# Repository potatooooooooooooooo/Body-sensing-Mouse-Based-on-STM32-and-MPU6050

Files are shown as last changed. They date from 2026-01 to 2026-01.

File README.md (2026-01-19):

## 项目简介
本项目是基于STM32和MPU6050的体感鼠标。项目通过使用Mahony算法实现姿态解算，利用无线模块实现数据传输，并最终实现了航姿仪姿态数据的实时解算与体感鼠标的姿态感应控制。

>本项目为本科课设，没想到过了近两年还有同学记得这个项目，于是直接开源到这里。
>当时做的比较简陋，欢迎大家在此基础上各显神通，做出更多好玩的东西。

## 项目功能
1.STM32采集传感器的数据，对姿态信息进行解算，并通过OLED屏幕进行显示，角度差小于1°。
2.按键控制LED灯的呼吸效果。
3.航姿仪系统发射端和体感鼠标接收端的板间通信，由无线模块接收姿态信息。
4.通过USB接口驱动电脑鼠标移动，实现左右键单双击等功能。

## 整体方案设计
STM32通过对传感器采集到的数据进行解算，得到当前姿态的数据，通过OLED屏幕对解算出的数据进行显示。通过按键来控制LED灯呼吸的效果。航姿仪系统方案设计设计总体框图如图：


在航姿仪的基础上，使用无线模块实现航姿仪与数据接收板之间的通信，数据接收板判断接收到的数据包合法后，与STM32之间采用SPI协议传输数据，然后根据传送的控制命令与PC进行USB HID交互，实现鼠标的上下左右移动以及单击双击效果。


本方案的设计思想是将航姿仪系统与无线通信技术相结合，通过数据解算和显示，以及无线传输，实现一个体感鼠标的功能。设计分为两个主要部分：航姿仪的发射端和数据接收板的接收端。

## 原理解析（硬件说明）
航姿仪电路主要包括STM32、电源模块、MPU6050模块、LED模块、OLED模块等几部分。航姿仪原理图如图：


数据接收板电路包括STM32、电源模块、无线模块和USB等几部分。数据接收板原理图如图：


硬件开源链接：
https://oshwhub.com/magic-stick/bang-bang-1-0
## 软件代码




## 实物图








## 补充测试
我们对航姿仪解算的角度进行了转台测试


得到三轴的测试数据如下：
横滚角roll测试数据：


俯仰角pitch测试数据：


偏航角yaw测试数据：


造成航姿仪数据误差可能是因为MPU6050陀螺仪本身的三轴加速度计并不正交，因此在程序初始化时就有误差而经过六面校准算法后的测试数据就好了很多。
偏航角无法通过加速度计进行校正数据，因此有较大的偏差。另外就是受限于陀螺仪本身的精度问题。

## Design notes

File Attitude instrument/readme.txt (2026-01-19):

key code

Device文件夹：
主要为外设驱动代码（oled，mpu6050，nrf24l01）
以及LED可变亮度呼吸流水灯逻辑代码

APP文件夹：
功能性算法代码
filters.c : 二阶IIR滤波器实现
ahrs.c    ：另一套解算算法，对比下来还是mahony更好一些
mahony.c  ：mahony姿态解算算法实现
imu_data.c: mpu6050数据预处理
commu.c	  : 与接收器通信的函数

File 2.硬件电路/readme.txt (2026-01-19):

使用嘉立创专业版导入文件
步骤：文件-导入-嘉立创专业版-选中.epro文件即可

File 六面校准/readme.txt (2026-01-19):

六个.txt文件内容分别代表：重力加速度沿某轴时三轴输出的原始数据（单位：m/s^2）

更新六个文件后运行test.m即可得到三轴加速度计矫正的比例系数及偏置系数

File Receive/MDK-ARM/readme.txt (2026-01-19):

key code：

main.c：轮训检测是否接收到数据
usb.c : 根据接收到数据内容填写报文

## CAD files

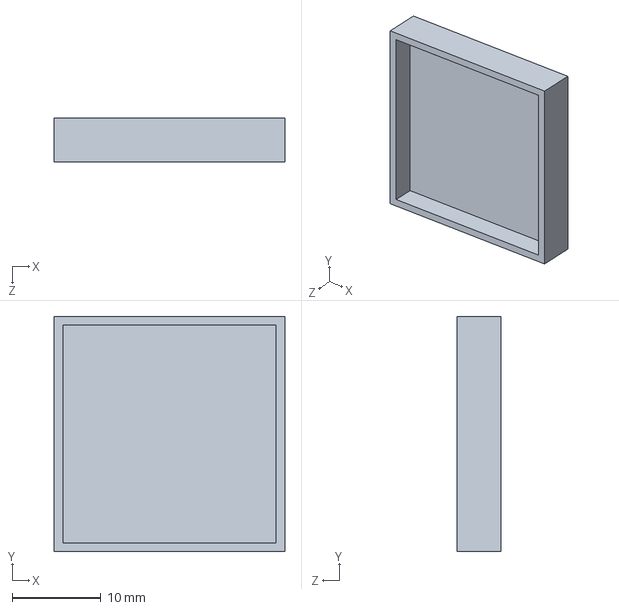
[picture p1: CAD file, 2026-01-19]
3.模型文件/接收器/gaizi2.1.SLDPRT
26.0 x 26.5 x 5.00 mm

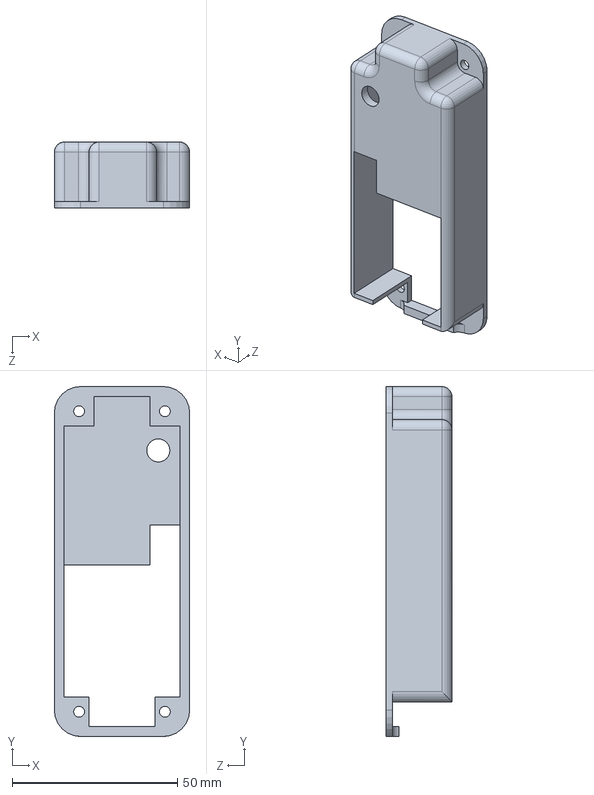
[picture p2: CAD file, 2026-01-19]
3.模型文件/航姿仪/gaizi2.0.SLDPRT
41.0 x 106.0 x 20.0 mm

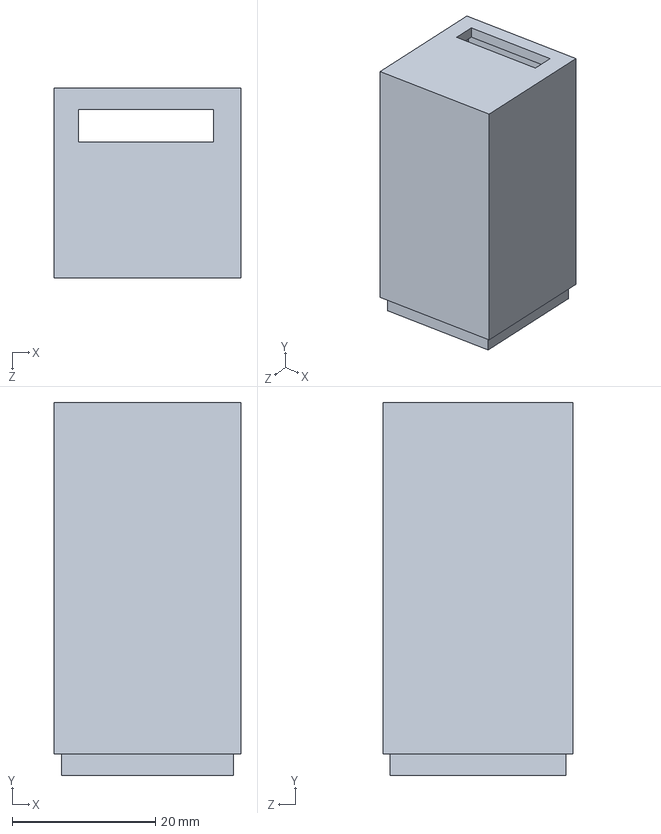
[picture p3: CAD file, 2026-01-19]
3.模型文件/接收器/hezi1.1.SLDPRT
26.0 x 52.0 x 26.5 mm

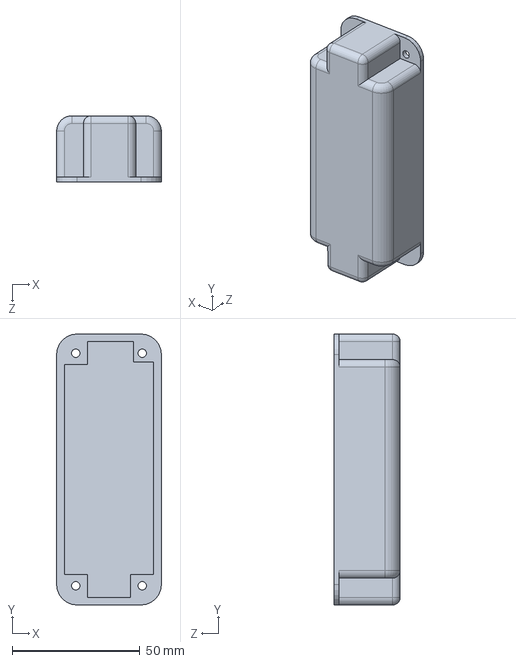
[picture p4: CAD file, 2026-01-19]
3.模型文件/航姿仪/hezi2.0.SLDPRT
41.0 x 106.0 x 26.0 mm

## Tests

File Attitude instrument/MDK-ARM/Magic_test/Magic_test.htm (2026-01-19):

# Static Call Graph for image Magic_test\Magic_test.axf

#<CALLGRAPH># ARM Linker, 5060960: Last Updated: Fri Sep 06 16:38:30 2024

### Maximum Stack Usage = 296 bytes + Unknown(Cycles, Untraceable Function Pointers)

### Call chain for Maximum Stack Depth:

TIM2_IRQHandler ⇒ HAL_TIM_IRQHandler ⇒ HAL_TIM_PeriodElapsedCallback ⇒ imuCalculateEstimatedAttitude ⇒ navi_prepare_imu_data ⇒ MPU_Get_Gyroscope ⇒ MPU_Read_Len ⇒ HAL_I2C_Mem_Read ⇒ I2C_RequestMemoryRead ⇒ I2C_WaitOnMasterAddressFlagUntilTimeout

### Mutually Recursive functions

- ADC1_2_IRQHandler ⇒ ADC1_2_IRQHandler
- BusFault_Handler ⇒ BusFault_Handler
- HardFault_Handler ⇒ HardFault_Handler
- MemManage_Handler ⇒ MemManage_Handler
- NMI_Handler ⇒ NMI_Handler
- UART_EndRxTransfer ⇒ UART_EndRxTransfer
- UsageFault_Handler ⇒ UsageFault_Handler

### Function Pointers

- ADC1_2_IRQHandler from startup_stm32f103xb.o(.text) referenced from startup_stm32f103xb.o(RESET)
- BusFault_Handler from stm32f1xx_it.o(i.BusFault_Handler) referenced from startup_stm32f103xb.o(RESET)
- CAN1_RX1_IRQHandler from startup_stm32f103xb.o(.text) referenced from startup_stm32f103xb.o(RESET)
- CAN1_SCE_IRQHandler from startup_stm32f103xb.o(.text) referenced from startup_stm32f103xb.o(RESET)
- DMA1_Channel1_IRQHandler from startup_stm32f103xb.o(.text) referenced from startup_stm32f103xb.o(RESET)
- DMA1_Channel2_IRQHandler from startup_stm32f103xb.o(.text) referenced from startup_stm32f103xb.o(RESET)
- DMA1_Channel3_IRQHandler from startup_stm32f103xb.o(.text) referenced from startup_stm32f103xb.o(RESET)
- DMA1_Channel4_IRQHandler from startup_stm32f103xb.o(.text) referenced from startup_stm32f103xb.o(RESET)
- DMA1_Channel5_IRQHandler from startup_stm32f103xb.o(.text) referenced from startup_stm32f103xb.o(RESET)
- DMA1_Channel6_IRQHandler from startup_stm32f103xb.o(.text) referenced from startup_stm32f103xb.o(RESET)
- DMA1_Channel7_IRQHandler from startup_stm32f103xb.o(.text) referenced from startup_stm32f103xb.o(RESET)
- DebugMon_Handler from stm32f1xx_it.o(i.DebugMon_Handler) referenced from startup_stm32f103xb.o(RESET)
- EXTI0_IRQHandler from startup_stm32f103xb.o(.text) referenced from startup_stm32f103xb.o(RESET)
- EXTI15_10_IRQHandler from startup_stm32f103xb.o(.text) referenced from startup_stm32f103xb.o(RESET)
- EXTI1_IRQHandler from startup_stm32f103xb.o(.text) referenced from startup_stm32f103xb.o(RESET)
- EXTI2_IRQHandler from startup_stm32f103xb.o(.text) referenced from startup_stm32f103xb.o(RESET)
- EXTI3_IRQHandler from startup_stm32f103xb.o(.text) referenced from startup_stm32f103xb.o(RESET)
- EXTI4_IRQHandler from startup_stm32f103xb.o(.text) referenced from startup_stm32f103xb.o(RESET)
- EXTI9_5_IRQHandler from startup_stm32f103xb.o(.text) referenced from startup_stm32f103xb.o(RESET)
- FLASH_IRQHandler from startup_stm32f103xb.o(.text) referenced from startup_stm32f103xb.o(RESET)
- HardFault_Handler from stm32f1xx_it.o(i.HardFault_Handler) referenced from startup_stm32f103xb.o(RESET)
- I2C1_ER_IRQHandler from startup_stm32f103xb.o(.text) referenced from startup_stm32f103xb.o(RESET)
- I2C1_EV_IRQHandler from startup_stm32f103xb.o(.text) referenced from startup_stm32f103xb.o(RESET)
- I2C2_ER_IRQHandler from startup_stm32f103xb.o(.text) referenced from startup_stm32f103xb.o(RESET)
- I2C2_EV_IRQHandler from startup_stm32f103xb.o(.text) referenced from startup_stm32f103xb.o(RESET)
- MemManage_Handler from stm32f1xx_it.o(i.MemManage_Handler) referenced from startup_stm32f103xb.o(RESET)
- NMI_Handler from stm32f1xx_it.o(i.NMI_Handler) referenced from startup_stm32f103xb.o(RESET)
- PVD_IRQHandler from startup_stm32f103xb.o(.text) referenced from startup_stm32f103xb.o(RESET)
- PendSV_Handler from stm32f1xx_it.o(i.PendSV_Handler) referenced from startup_stm32f103xb.o(RESET)
- RCC_IRQHandler from startup_stm32f103xb.o(.text) referenced from startup_stm32f103xb.o(RESET)
- RTC_Alarm_IRQHandler from startup_stm32f103xb.o(.text) referenced from startup_stm32f103xb.o(RESET)
- RTC_IRQHandler from startup_stm32f103xb.o(.text) referenced from startup_stm32f103xb.o(RESET)
- Reset_Handler from startup_stm32f103xb.o(.text) referenced from startup_stm32f103xb.o(RESET)
- SPI1_IRQHandler from startup_stm32f103xb.o(.text) referenced from startup_stm32f103xb.o(RESET)
- SPI2_IRQHandler from stm32f1xx_it.o(i.SPI2_IRQHandler) referenced from startup_stm32f103xb.o(RESET)
- SPI_DMAAbortOnError from stm32f1xx_hal_spi.o(i.SPI_DMAAbortOnError) referenced from stm32f1xx_hal_spi.o(i.HAL_SPI_IRQHandler)
- SVC_Handler from stm32f1xx_it.o(i.SVC_Handler) referenced from startup_stm32f103xb.o(RESET)
- SysTick_Handler from stm32f1xx_it.o(i.SysTick_Handler) referenced from startup_stm32f103xb.o(RESET)
- SystemInit from system_stm32f1xx.o(i.SystemInit) referenced from startup_stm32f103xb.o(.text)
- TAMPER_IRQHandler from startup_stm32f103xb.o(.text) referenced from startup_stm32f103xb.o(RESET)
- TIM1_BRK_IRQHandler from startup_stm32f103xb.o(.text) referenced from startup_stm32f103xb.o(RESET)
- TIM1_CC_IRQHandler from startup_stm32f103xb.o(.text) referenced from startup_stm32f103xb.o(RESET)
- TIM1_TRG_COM_IRQHandler from startup_stm32f103xb.o(.text) referenced from startup_stm32f103xb.o(RESET)
- TIM1_UP_IRQHandler from startup_stm32f103xb.o(.text) referenced from startup_stm32f103xb.o(RESET)
- TIM2_IRQHandler from stm32f1xx_it.o(i.TIM2_IRQHandler) referenced from startup_stm32f103xb.o(RESET)
- TIM3_IRQHandler from startup_stm32f103xb.o(.text) referenced from startup_stm32f103xb.o(RESET)
- TIM4_IRQHandler from startup_stm32f103xb.o(.text) referenced from startup_stm32f103xb.o(RESET)
- UART_DMAAbortOnError from stm32f1xx_hal_uart.o(i.UART_DMAAbortOnError) referenced from stm32f1xx_hal_uart.o(i.HAL_UART_IRQHandler)
- USART1_IRQHandler from stm32f1xx_it.o(i.USART1_IRQHandler) referenced from startup_stm32f103xb.o(RESET)
- USART2_IRQHandler from startup_stm32f103xb.o(.text) referenced from startup_stm32f103xb.o(RESET)
- USART3_IRQHandler from startup_stm32f103xb.o(.text) referenced from startup_stm32f103xb.o(RESET)
- USBWakeUp_IRQHandler from startup_stm32f103xb.o(.text) referenced from startup_stm32f103xb.o(RESET)
- USB_HP_CAN1_TX_IRQHandler from startup_stm32f103xb.o(.text) referenced from startup_stm32f103xb.o(RESET)
- USB_LP_CAN1_RX0_IRQHandler from startup_stm32f103xb.o(.text) referenced from startup_stm32f103xb.o(RESET)
- UsageFault_Handler from stm32f1xx_it.o(i.UsageFault_Handler) referenced from startup_stm32f103xb.o(RESET)
- WWDG_IRQHandler from startup_stm32f103xb.o(.text) referenced from startup_stm32f103xb.o(RESET)
- __main from entry.o(.ARM.Collect$$$$00000000) referenced from startup_stm32f103xb.o(.text)
- fputc from main.o(i.fputc) referenced from printf6.o(i.__0printf$6)
- main from main.o(i.main) referenced from entry9a.o(.ARM.Collect$$$$0000000B)

### Global Symbols

__main (Thumb, 0 bytes, Stack size unknown bytes, entry.o(.ARM.Collect$$$$00000000))
[Address Reference Count : 1]

- startup_stm32f103xb.o(.text)

_main_stk (Thumb, 0 bytes, Stack size unknown bytes, entry2.o(.ARM.Collect$$$$00000001))

_main_scatterload (Thumb, 0 bytes, Stack size unknown bytes, entry5.o(.ARM.Collect$$$$00000004))

[Calls]

- >> __scatterload

__main_after_scatterload (Thumb, 0 bytes, Stack size unknown bytes, entry5.o(.ARM.Collect$$$$00000004))

[Called By]

- >> __scatterload

_main_clock (Thumb, 0 bytes, Stack size unknown bytes, entry7b.o(.ARM.Collect$$$$00000008))

_main_cpp_init (Thumb, 0 bytes, Stack size unknown bytes, entry8b.o(.ARM.Collect$$$$0000000A))

_main_init (Thumb, 0 bytes, Stack size unknown bytes, entry9a.o(.ARM.Collect$$$$0000000B))

__rt_lib_shutdown_fini (Thumb, 0 bytes, Stack size unknown bytes, entry12b.o(.ARM.Collect$$$$0000000E))

__rt_final_cpp (Thumb, 0 bytes, Stack size unknown bytes, entry10a.o(.ARM.Collect$$$$0000000F))

__rt_final_exit (Thumb, 0 bytes, Stack size unknown bytes, entry11a.o(.ARM.Collect$$$$00000011))

Reset_Handler (Thumb, 8 bytes, Stack size 0 bytes, startup_stm32f103xb.o(.text))
[Address Reference Count : 1]

- startup_stm32f103xb.o(RESET)

ADC1_2_IRQHandler (Thumb, 0 bytes, Stack size 0 bytes, startup_stm32f103xb.o(.text))

[Calls]

- >> ADC1_2_IRQHandler

[Called By]

- >> ADC1_2_IRQHandler

[Address Reference Count : 1]

- startup_stm32f103xb.o(RESET)

CAN1_RX1_IRQHandler (Thumb, 0 bytes, Stack size 0 bytes, startup_stm32f103xb.o(.text))
[Address Reference Count : 1]

- startup_stm32f103xb.o(RESET)

CAN1_SCE_IRQHandler (Thumb, 0 bytes, Stack size 0 bytes, startup_stm32f103xb.o(.text))
[Address Reference Count : 1]

- startup_stm32f103xb.o(RESET)

DMA1_Channel1_IRQHandler (Thumb, 0 bytes, Stack size 0 bytes, startup_stm32f103xb.o(.text))
[Address Reference Count : 1]

- startup_stm32f103xb.o(RESET)

DMA1_Channel2_IRQHandler (Thumb, 0 bytes, Stack size 0 bytes, startup_stm32f103xb.o(.text))
[Address Reference Count : 1]

- startup_stm32f103xb.o(RESET)

DMA1_Channel3_IRQHandler (Thumb, 0 bytes, Stack size 0 bytes, startup_stm32f103xb.o(.text))
[Address Reference Count : 1]

- startup_stm32f103xb.o(RESET)

DMA1_Channel4_IRQHandler (Thumb, 0 bytes, Stack size 0 bytes, startup_stm32f103xb.o(.text))
[Address Reference Count : 1]

- startup_stm32f103xb.o(RESET)

DMA1_Channel5_IRQHandler (Thumb, 0 bytes, Stack size 0 bytes, startup_stm32f103xb.o(.text))
[Address Reference Count : 1]

- startup_stm32f103xb.o(RESET)

DMA1_Channel6_IRQHandler (Thumb, 0 bytes, Stack size 0 bytes, startup_stm32f103xb.o(.text))
[Address Reference Count : 1]

- startup_stm32f103xb.o(RESET)

DMA1_Channel7_IRQHandler (Thumb, 0 bytes, Stack size 0 bytes, startup_stm32f103xb.o(.text))
[Address Reference Count : 1]

- startup_stm32f103xb.o(RESET)

EXTI0_IRQHandler (Thumb, 0 bytes, Stack size 0 bytes, startup_stm32f103xb.o(.text))
[Address Reference Count : 1]

- startup_stm32f103xb.o(RESET)

EXTI15_10_IRQHandler (Thumb, 0 bytes, Stack size 0 bytes, startup_stm32f103xb.o(.text))
[Address Reference Count : 1]

- startup_stm32f103xb.o(RESET)

EXTI1_IRQHandler (Thumb, 0 bytes, Stack size 0 bytes, startup_stm32f103xb.o(.text))
[Address Reference Count : 1]

- startup_stm32f103xb.o(RESET)

EXTI2_IRQHandler (Thumb, 0 bytes, Stack size 0 bytes, startup_stm32f103xb.o(.text))
[Address Reference Count : 1]

- startup_stm32f103xb.o(RESET)

EXTI3_IRQHandler (Thumb, 0 bytes, Stack size 0 bytes, startup_stm32f103xb.o(.text))
[Address Reference Count : 1]

- startup_stm32f103xb.o(RESET)

EXTI4_IRQHandler (Thumb, 0 bytes, Stack size 0 bytes, startup_stm32f103xb.o(.text))
[Address Reference Count : 1]

- startup_stm32f103xb.o(RESET)

EXTI9_5_IRQHandler (Thumb, 0 bytes, Stack size 0 bytes, startup_stm32f103xb.o(.text))
[Address Reference Count : 1]

- startup_stm32f103xb.o(RESET)

FLASH_IRQHandler (Thumb, 0 bytes, Stack size 0 bytes, startup_stm32f103xb.o(.text))
[Address Reference Count : 1]

- startup_stm32f103xb.o(RESET)

I2C1_ER_IRQHandler (Thumb, 0 bytes, Stack size 0 bytes, startup_stm32f103xb.o(.text))
[Address Reference Count : 1]

- startup_stm32f103xb.o(RESET)

I2C1_EV_IRQHandler (Thumb, 0 bytes, Stack size 0 bytes, startup_stm32f103xb.o(.text))
[Address Reference Count : 1]

- startup_stm32f103xb.o(RESET)

I2C2_ER_IRQHandler (Thumb, 0 bytes, Stack size 0 bytes, startup_stm32f103xb.o(.text))
[Address Reference Count : 1]

- startup_stm32f103xb.o(RESET)

I2C2_EV_IRQHandler (Thumb, 0 bytes, Stack size 0 bytes, startup_stm32f103xb.o(.text))
[Address Reference Count : 1]

- startup_stm32f103xb.o(RESET)

PVD_IRQHandler (Thumb, 0 bytes, Stack size 0 bytes, startup_stm32f103xb.o(.text))
[Address Reference Count : 1]

- startup_stm32f103xb.o(RESET)

RCC_IRQHandler (Thumb, 0 bytes, Stack size 0 bytes, startup_stm32f103xb.o(.text))
[Address Reference Count : 1]

- startup_stm32f103xb.o(RESET)

RTC_Alarm_IRQHandler (Thumb, 0 bytes, Stack size 0 bytes, startup_stm32f103xb.o(.text))
[Address Reference Count : 1]

- startup_stm32f103xb.o(RESET)

RTC_IRQHandler (Thumb, 0 bytes, Stack size 0 bytes, startup_stm32f103xb.o(.text))
[Address Reference Count : 1]

- startup_stm32f103xb.o(RESET)

SPI1_IRQHandler (Thumb, 0 bytes, Stack size 0 bytes, startup_stm32f103xb.o(.text))
[Address Reference Count : 1]

- startup_stm32f103xb.o(RESET)

TAMPER_IRQHandler (Thumb, 0 bytes, Stack size 0 bytes, startup_stm32f103xb.o(.text))
[Address Reference Count : 1]

- startup_stm32f103xb.o(RESET)

TIM1_BRK_IRQHandler (Thumb, 0 bytes, Stack size 0 bytes, startup_stm32f103xb.o(.text))
[Address Reference Count : 1]

- startup_stm32f103xb.o(RESET)

TIM1_CC_IRQHandler (Thumb, 0 bytes, Stack size 0 bytes, startup_stm32f103xb.o(.text))
[Address Reference Count : 1]

- startup_stm32f103xb.o(RESET)

TIM1_TRG_COM_IRQHandler (Thumb, 0 bytes, Stack size 0 bytes, startup_stm32f103xb.o(.text))
[Address Reference Count : 1]

- startup_stm32f103xb.o(RESET)

TIM1_UP_IRQHandler (Thumb, 0 bytes, Stack size 0 bytes, startup_stm32f103xb.o(.text))
[Address Reference Count : 1]

- startup_stm32f103xb.o(RESET)

TIM3_IRQHandler (Thumb, 0 bytes, Stack size 0 bytes, startup_stm32f103xb.o(.text))
[Address Reference Count : 1]

- startup_stm32f103xb.o(RESET)

TIM4_IRQHandler (Thumb, 0 bytes, Stack size 0 bytes, startup_stm32f103xb.o(.text))
[Address Reference Count : 1]

- startup_stm32f103xb.o(RESET)

USART2_IRQHandler (Thumb, 0 bytes, Stack size 0 bytes, startup_stm32f103xb.o(.text))
[Address Reference Count : 1]

- startup_stm32f103xb.o(RESET)

USART3_IRQHandler (Thumb, 0 bytes, Stack size 0 bytes, startup_stm32f103xb.o(.text))
[Address Reference Count : 1]

- startup_stm32f103xb.o(RESET)

USBWakeUp_IRQHandler (Thumb, 0 bytes, Stack size 0 bytes, startup_stm32f103xb.o(.text))
[Address Reference Count : 1]

- startup_stm32f103xb.o(RESET)

USB_HP_CAN1_TX_IRQHandler (Thumb, 0 bytes, Stack size 0 bytes, startup_stm32f103xb.o(.text))
[Address Reference Count : 1]

- startup_stm32f103xb.o(RESET)

USB_LP_CAN1_RX0_IRQHandler (Thumb, 0 bytes, Stack size 0 bytes, startup_stm32f103xb.o(.text))
[Address Reference Count : 1]

- startup_stm32f103xb.o(RESET)

WWDG_IRQHandler (Thumb, 0 bytes, Stack size 0 bytes, startup_stm32f103xb.o(.text))
[Address Reference Count : 1]

- startup_stm32f103xb.o(RESET)

__aeabi_llsr (Thumb, 32 bytes, Stack size 0 bytes, llushr.o(.text))

[Called By]

- >> _double_epilogue

_ll_ushift_r (Thumb, 0 bytes, Stack size 0 bytes, llushr.o(.text), UNUSED)

__aeabi_memcpy (Thumb, 36 bytes, Stack size 0 bytes, memcpya.o(.text), UNUSED)

__aeabi_memcpy4 (Thumb, 0 bytes, Stack size 0 bytes, memcpya.o(.text))

[Called By]

- >> FusionAhrsInitialise

__aeabi_memcpy8 (Thumb, 0 bytes, Stack size 0 bytes, memcpya.o(.text), UNUSED)

__aeabi_memset (Thumb, 14 bytes, Stack size 0 bytes, memseta.o(.text), UNUSED)

[Called By]

- >> _memset$wrapper
- >> __aeabi_memclr

__aeabi_memset4 (Thumb, 0 bytes, Stack size 0 bytes, memseta.o(.text), UNUSED)

__aeabi_memset8 (Thumb, 0 bytes, Stack size 0 bytes, memseta.o(.text), UNUSED)

__aeabi_memclr (Thumb, 4 bytes, Stack size 0 bytes, memseta.o(.text), UNUSED)

[Calls]

- >> __aeabi_memset

__aeabi_memclr4 (Thumb, 0 bytes, Stack size 0 bytes, memseta.o(.text))

[Called By]

- >> MX_TIM4_Init
- >> MX_TIM1_Init
- >> SystemClock_Config

__aeabi_memclr8 (Thumb, 0 bytes, Stack size 0 bytes, memseta.o(.text), UNUSED)

_memset$wrapper (Thumb, 18 bytes, Stack size 8 bytes, memseta.o(.text), UNUSED)

[Calls]

- >> __aeabi_memset

__aeabi_fadd (Thumb, 164 bytes, Stack size 16 bytes, fadd.o(.text))

[Stack]

- Max Depth = 20
- Call Chain = __aeabi_fadd ⇒ _float_epilogue

[Calls]

- >> _float_round
- >> _float_epilogue

[Called By]

- >> tanf
- >> sinf
- >> powf
- >> cosf
- >> atan2f
- >> asinf
- >> imuInit
- >> imuMahonyAHRSupdate
- >> imuComputeRotationMatrix
- >> navi_prepare_imu_data
- >> __aeabi_fsub
- >> __aeabi_frsub
- >> get_iir_output
- >> cal_iir_coeff
- >> __mathlib_rredf2
- >> __mathlib_flt_infnan2

__aeabi_fsub (Thumb, 6 bytes, Stack size 0 bytes, fadd.o(.text))

[Stack]

- Max Depth = 20
- Call Chain = __aeabi_fsub ⇒ __aeabi_fadd ⇒ _float_epilogue

[Calls]

- >> __aeabi_fadd

[Called By]

- >> FusionAhrsSetSettings
- >> tanf
- >> sinf
- >> powf
- >> cosf
- >> atan2f
- >> imuInit
- >> imuMahonyAHRSupdate
- >> imuComputeRotationMatrix
- >> get_iir_output
- >> cal_iir_coeff
- >> __mathlib_rredf2

__aeabi_frsub (Thumb, 6 bytes, Stack size 0 bytes, fadd.o(.text))

[Stack]

- Max Depth = 20
- Call Chain = __aeabi_frsub ⇒ __aeabi_fadd ⇒ _float_epilogue

[Calls]

- >> __aeabi_fadd

[Called By]

- >> tanf
- >> sinf
- >> powf
- >> cosf
- >> atan2f
- >> asinf
- >> imuComputeRotationMatrix
- >> get_iir_output
- >> cal_iir_coeff
- >> __mathlib_rredf2

__aeabi_fmul (Thumb, 100 bytes, Stack size 8 bytes, fmul.o(.text))

[Stack]

- Max Depth = 8
- Call Chain = __aeabi_fmul

[Called By]

- >> FusionAhrsSetSettings
- >> FusionDegreesToRadians
- >> tanf
- >> sinf
- >> powf
- >> cosf
- >> atan2f
- >> asinf
- >> imuInit
- >> imuUpdateEulerAngles
- >> imuMahonyAHRSupdate
- >> imuComputeRotationMatrix
- >> navi_prepare_imu_data
- >> get_iir_output
- >> cal_iir_coeff
- >> OLED_ShowFNum
- >> __mathlib_rredf2

__aeabi_fdiv (Thumb, 124 bytes, Stack size 8 bytes, fdiv.o(.text))

[Stack]

- Max Depth = 8
- Call Chain = __aeabi_fdiv

[Calls]

- >> _float_round

[Called By]

- >> FusionAhrsSetSettings
- >> tanf
- >> powf
- >> atan2f
- >> invSqrt
- >> cal_iir_coeff
- >> LED_Callback
- >> main
- >> __mathlib_flt_invalid
- >> __mathlib_flt_divzero

__ARM_scalbnf (Thumb, 24 bytes, Stack size 0 bytes, fscalb.o(.text))

[Called By]

- >> FusionAhrsSetSettings
- >> powf
- >> asinf
- >> imuInit
- >> imuMahonyAHRSupdate
- >> imuComputeRotationMatrix
- >> navi_prepare_imu_data
- >> cal_iir_coeff
- >> __mathlib_rredf2
- >> __mathlib_flt_underflow
- >> __mathlib_flt_overflow
- >> __mathlib_flt_infnan

scalbnf (Thumb, 0 bytes, Stack size 0 bytes, fscalb.o(.text), UNUSED)

__aeabi_dadd (Thumb, 322 bytes, Stack size 48 bytes, dadd.o(.text))

[Stack]

- Max Depth = 88
- Call Chain = __aeabi_dadd ⇒ _double_epilogue ⇒ _double_round

[Calls]

- >> __aeabi_lasr
- >> __aeabi_llsl
- >> _double_round
- >> _double_epilogue

[Called By]

- >> __aeabi_dsub
- >> navi_glory_sum_offset
- >> __aeabi_drsub

__aeabi_dsub (Thumb, 6 bytes, Stack size 0 bytes, dadd.o(.text))

[Stack]

- Max Depth = 88
- Call Chain = __aeabi_dsub ⇒ __aeabi_dadd ⇒ _double_epilogue ⇒ _double_round

[Calls]

- >> __aeabi_dadd

[Called By]

- >> navi_prepare_imu_data

__aeabi_drsub (Thumb, 6 bytes, Stack size 0 bytes, dadd.o(.text), UNUSED)

[Calls]

- >> __aeabi_dadd

__aeabi_dmul (Thumb, 228 bytes, Stack size 48 bytes, dmul.o(.text))

[Stack]

- Max Depth = 88
- Call Chain = __aeabi_dmul ⇒ _double_epilogue ⇒ _double_round

[Calls]

- >> _double_epilogue

[Called By]

- >> navi_prepare_imu_data

__aeabi_ddiv (Thumb, 222 bytes, Stack size 32 bytes, ddiv.o(.text))

[Stack]

- Max Depth = 40
- Call Chain = __aeabi_ddiv ⇒ _double_round

[Calls]

- >> _double_round

[Called By]

- >> navi_prepare_imu_data
- >> navi_glory_sum_offset

__aeabi_i2f (Thumb, 18 bytes, Stack size 0 bytes, fflti.o(.text))

[Stack]

- Max Depth = 4
- Call Chain = __aeabi_i2f ⇒ _float_epilogue

[Calls]

- >> _float_epilogue

[Called By]

- >> powf
- >> imuInit
- >> navi_prepare_imu_data
- >> LED_Callback
- >> main
- >> __mathlib_rredf2

__aeabi_ui2f (Thumb, 10 bytes, Stack size 0 bytes, ffltui.o(.text))

[Stack]

- Max Depth = 4
- Call Chain = __aeabi_ui2f ⇒ _float_epilogue

[Calls]

- >> _float_epilogue

[Called By]

- >> OLED_ShowFNum
- >> __mathlib_rredf2

__aeabi_i2d (Thumb, 34 bytes, Stack size 16 bytes, dflti.o(.text))

[Stack]

- Max Depth = 56
- Call Chain = __aeabi_i2d ⇒ _double_epilogue ⇒ _double_round

[Calls]

- >> _double_epilogue

[Called By]

- >> navi_prepare_imu_data

__aeabi_f2iz (Thumb, 50 bytes, Stack size 0 bytes, ffixi.o(.text))

[Called By]

- >> data_process
- >> tanf
- >> sinf
- >> cosf
- >> OLED_ShowFNum
- >> LED_Callback

__aeabi_f2d (Thumb, 38 bytes, Stack size 0 bytes, f2d.o(.text))

[Called By]

- >> navi_prepare_imu_data
- >> navi_glory_sum_offset

__aeabi_d2f (Thumb, 56 bytes, Stack size 8 bytes, d2f.o(.text))

[Stack]

- Max Depth = 8
- Call Chain = __aeabi_d2f

[Calls]

- >> _float_round

[Called By]

- >> navi_prepare_imu_data

__aeabi_uidiv (Thumb, 0 bytes, Stack size 12 bytes, uidiv.o(.text), UNUSED)

__aeabi_uidivmod (Thumb, 44 bytes, Stack size 12 bytes, uidiv.o(.text), UNUSED)

[Called By]

- >> _printf_core

__aeabi_llsl (Thumb, 30 bytes, Stack size 0 bytes, llshl.o(.text))

[Called By]

- >> __aeabi_dadd
- >> _double_epilogue

_ll_shift_l (Thumb, 0 bytes, Stack size 0 bytes, llshl.o(.text), UNUSED)

__aeabi_lasr (Thumb, 36 bytes, Stack size 0 bytes, llsshr.o(.text))

[Called By]

- >> __aeabi_dadd

_ll_sshift_r (Thumb, 0 bytes, Stack size 0 bytes, llsshr.o(.text), UNUSED)

__I$use$fp (Thumb, 0 bytes, Stack size 0 bytes, iusefp.o(.text), UNUSED)

_float_round (Thumb, 18 bytes, Stack size 0 bytes, fepilogue.o(.text))

[Called By]

- >> _fsqrt
- >> _ffix_r
- >> _frnd
- >> __aeabi_d2f
- >> __aeabi_fadd
- >> __aeabi_fdiv

_float_epilogue (Thumb, 92 bytes, Stack size 4 bytes, fepilogue.o(.text))

[Stack]

- Max Depth = 4
- Call Chain = _float_epilogue

[Called By]

- >> __aeabi_ui2f
- >> __aeabi_fadd
- >> __aeabi_i2f

_fsqrt (Thumb, 94 bytes, Stack size 16 bytes, fsqrt.o(.text))

[Stack]

- Max Depth = 16
- Call Chain = _fsqrt

[Calls]

- >> _float_round

[Called By]

- >> sqrtf

_frnd (Thumb, 60 bytes, Stack size 8 bytes, frnd.o(.text))

[Stack]

- Max Depth = 8
- Call Chain = _frnd

[Calls]

- >> _float_round

[Called By]

- >> tanf
- >> sinf
- >> cosf

_double_round (Thumb, 30 bytes, Stack size 8 bytes, depilogue.o(.text))

[Stack]

- Max Depth = 8
- Call Chain = _double_round

[Called By]

- >> __aeabi_dadd
- >> __aeabi_ddiv
- >> _double_epilogue

_double_epilogue (Thumb, 156 bytes, Stack size 32 bytes, depilogue.o(.text))

[Stack]

- Max Depth = 40
- Call Chain = _double_epilogue ⇒ _double_round

[Calls]

- >> __aeabi_llsr
- >> __aeabi_llsl
- >> _double_round

[Called By]

- >> __aeabi_i2d
- >> __aeabi_dmul
- >> __aeabi_dadd

_ffix_r (Thumb, 76 bytes, Stack size 8 bytes, ffixir.o(.text))

[Stack]

- Max Depth = 8
- Call Chain = _ffix_r

[Calls]

- >> _float_round

[Called By]

- >> powf

__fp_status (Thumb, 4 bytes, Stack size 0 bytes, fpstat.o(.text), UNUSED)

__ieee_status (Thumb, 0 bytes, Stack size 0 bytes, fpstat.o(.text))

[Called By]

- >> powf

__scatterload (Thumb, 28 bytes, Stack size 0 bytes, init.o(.text))

[Calls]

- >> __main_after_scatterload

[Called By]

- >> _main_scatterload

__scatterload_rt2 (Thumb, 0 bytes, Stack size 0 bytes, init.o(.text), UNUSED)

BusFault_Handler (Thumb, 2 bytes, Stack size 0 bytes, stm32f1xx_it.o(i.BusFault_Handler))

[Calls]

- >> BusFault_Handler

[Called By]

- >> BusFault_Handler

[Address Reference Count : 1]

- startup_stm32f103xb.o(RESET)

DebugMon_Handler (Thumb, 2 bytes, Stack size 0 bytes, stm32f1xx_it.o(i.DebugMon_Handler))
[Address Reference Count : 1]

- startup_stm32f103xb.o(RESET)

Error_Handler (Thumb, 4 bytes, Stack size 0 bytes, main.o(i.Error_Handler))

[Called By]

- >> MX_USART1_UART_Init
- >> MX_TIM4_Init
- >> MX_TIM2_Init
- >> MX_TIM1_Init
- >> MX_SPI2_Init
- >> MX_I2C2_Init

Filter_init (Thumb, 72 bytes, Stack size 16 bytes, imu_data.o(i.Filter_init))

[Stack]

- Max Depth = 140
- Call Chain = Filter_init ⇒ cal_iir_coeff ⇒ tanf ⇒ __mathlib_rredf2 ⇒ __aeabi_fsub ⇒ __aeabi_fadd ⇒ _float_epilogue

[Calls]

- >> cal_iir_coeff

[Called By]

- >> main

FusionAhrsInitialise (Thumb, 34 bytes, Stack size 32 bytes, fusionahrs.o(i.FusionAhrsInitialise))

[Stack]

- Max Depth = 140
- Call Chain = FusionAhrsInitialise ⇒ FusionAhrsSetSettings ⇒ sinf ⇒ __mathlib_rredf2 ⇒ __aeabi_fsub ⇒ __aeabi_fadd ⇒ _float_epilogue

[Calls]

- >> FusionAhrsSetSettings
- >> FusionAhrsReset
- >> __aeabi_memcpy4

[Called By]

- >> main

FusionAhrsReset (Thumb, 68 bytes, Stack size 8 bytes, fusionahrs.o(i.FusionAhrsReset))

[Stack]

- Max Depth = 8
- Call Chain = FusionAhrsReset

[Called By]

- >> FusionAhrsInitialise
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

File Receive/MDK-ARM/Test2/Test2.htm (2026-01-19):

# Static Call Graph for image Test2\Test2.axf

#<CALLGRAPH># ARM Linker, 5060960: Last Updated: Fri Sep 06 16:41:52 2024

### Maximum Stack Usage = 216 bytes + Unknown(Cycles, Untraceable Function Pointers)

### Call chain for Maximum Stack Depth:

main ⇒ NRF24L01_RxPacket ⇒ NRF24L01_Read_Buf ⇒ SPIx_ReadWriteByte ⇒ HAL_SPI_TransmitReceive ⇒ SPI_EndRxTxTransaction ⇒ SPI_WaitFlagStateUntilTimeout

### Mutually Recursive functions

- CAN1_RX1_IRQHandler ⇒ CAN1_RX1_IRQHandler
- BusFault_Handler ⇒ BusFault_Handler
- HardFault_Handler ⇒ HardFault_Handler
- MemManage_Handler ⇒ MemManage_Handler
- NMI_Handler ⇒ NMI_Handler
- UART_EndRxTransfer ⇒ UART_EndRxTransfer
- UsageFault_Handler ⇒ UsageFault_Handler

### Function Pointers

- ADC1_2_IRQHandler from stm32f1xx_it.o(i.ADC1_2_IRQHandler) referenced from startup_stm32f103xb.o(RESET)
- BusFault_Handler from stm32f1xx_it.o(i.BusFault_Handler) referenced from startup_stm32f103xb.o(RESET)
- CAN1_RX1_IRQHandler from startup_stm32f103xb.o(.text) referenced from startup_stm32f103xb.o(RESET)
- CAN1_SCE_IRQHandler from startup_stm32f103xb.o(.text) referenced from startup_stm32f103xb.o(RESET)
- DMA1_Channel1_IRQHandler from startup_stm32f103xb.o(.text) referenced from startup_stm32f103xb.o(RESET)
- DMA1_Channel2_IRQHandler from startup_stm32f103xb.o(.text) referenced from startup_stm32f103xb.o(RESET)
- DMA1_Channel3_IRQHandler from startup_stm32f103xb.o(.text) referenced from startup_stm32f103xb.o(RESET)
- DMA1_Channel4_IRQHandler from startup_stm32f103xb.o(.text) referenced from startup_stm32f103xb.o(RESET)
- DMA1_Channel5_IRQHandler from startup_stm32f103xb.o(.text) referenced from startup_stm32f103xb.o(RESET)
- DMA1_Channel6_IRQHandler from startup_stm32f103xb.o(.text) referenced from startup_stm32f103xb.o(RESET)
- DMA1_Channel7_IRQHandler from startup_stm32f103xb.o(.text) referenced from startup_stm32f103xb.o(RESET)
- DebugMon_Handler from stm32f1xx_it.o(i.DebugMon_Handler) referenced from startup_stm32f103xb.o(RESET)
- EXTI0_IRQHandler from startup_stm32f103xb.o(.text) referenced from startup_stm32f103xb.o(RESET)
- EXTI15_10_IRQHandler from startup_stm32f103xb.o(.text) referenced from startup_stm32f103xb.o(RESET)
- EXTI1_IRQHandler from startup_stm32f103xb.o(.text) referenced from startup_stm32f103xb.o(RESET)
- EXTI2_IRQHandler from startup_stm32f103xb.o(.text) referenced from startup_stm32f103xb.o(RESET)
- EXTI3_IRQHandler from startup_stm32f103xb.o(.text) referenced from startup_stm32f103xb.o(RESET)
- EXTI4_IRQHandler from startup_stm32f103xb.o(.text) referenced from startup_stm32f103xb.o(RESET)
- EXTI9_5_IRQHandler from startup_stm32f103xb.o(.text) referenced from startup_stm32f103xb.o(RESET)
- FLASH_IRQHandler from startup_stm32f103xb.o(.text) referenced from startup_stm32f103xb.o(RESET)
- HardFault_Handler from stm32f1xx_it.o(i.HardFault_Handler) referenced from startup_stm32f103xb.o(RESET)
- I2C1_ER_IRQHandler from startup_stm32f103xb.o(.text) referenced from startup_stm32f103xb.o(RESET)
- I2C1_EV_IRQHandler from startup_stm32f103xb.o(.text) referenced from startup_stm32f103xb.o(RESET)
- I2C2_ER_IRQHandler from startup_stm32f103xb.o(.text) referenced from startup_stm32f103xb.o(RESET)
- I2C2_EV_IRQHandler from startup_stm32f103xb.o(.text) referenced from startup_stm32f103xb.o(RESET)
- MemManage_Handler from stm32f1xx_it.o(i.MemManage_Handler) referenced from startup_stm32f103xb.o(RESET)
- NMI_Handler from stm32f1xx_it.o(i.NMI_Handler) referenced from startup_stm32f103xb.o(RESET)
- PVD_IRQHandler from startup_stm32f103xb.o(.text) referenced from startup_stm32f103xb.o(RESET)
- PendSV_Handler from stm32f1xx_it.o(i.PendSV_Handler) referenced from startup_stm32f103xb.o(RESET)
- RCC_IRQHandler from startup_stm32f103xb.o(.text) referenced from startup_stm32f103xb.o(RESET)
- RTC_Alarm_IRQHandler from startup_stm32f103xb.o(.text) referenced from startup_stm32f103xb.o(RESET)
- RTC_IRQHandler from startup_stm32f103xb.o(.text) referenced from startup_stm32f103xb.o(RESET)
- Reset_Handler from startup_stm32f103xb.o(.text) referenced from startup_stm32f103xb.o(RESET)
- SPI1_IRQHandler from startup_stm32f103xb.o(.text) referenced from startup_stm32f103xb.o(RESET)
- SPI2_IRQHandler from stm32f1xx_it.o(i.SPI2_IRQHandler) referenced from startup_stm32f103xb.o(RESET)
- SPI_DMAAbortOnError from stm32f1xx_hal_spi.o(i.SPI_DMAAbortOnError) referenced from stm32f1xx_hal_spi.o(i.HAL_SPI_IRQHandler)
- SVC_Handler from stm32f1xx_it.o(i.SVC_Handler) referenced from startup_stm32f103xb.o(RESET)
- SysTick_Handler from stm32f1xx_it.o(i.SysTick_Handler) referenced from startup_stm32f103xb.o(RESET)
- SystemInit from system_stm32f1xx.o(i.SystemInit) referenced from startup_stm32f103xb.o(.text)
- TAMPER_IRQHandler from startup_stm32f103xb.o(.text) referenced from startup_stm32f103xb.o(RESET)
- TIM1_BRK_IRQHandler from startup_stm32f103xb.o(.text) referenced from startup_stm32f103xb.o(RESET)
- TIM1_CC_IRQHandler from startup_stm32f103xb.o(.text) referenced from startup_stm32f103xb.o(RESET)
- TIM1_TRG_COM_IRQHandler from startup_stm32f103xb.o(.text) referenced from startup_stm32f103xb.o(RESET)
- TIM1_UP_IRQHandler from startup_stm32f103xb.o(.text) referenced from startup_stm32f103xb.o(RESET)
- TIM2_IRQHandler from startup_stm32f103xb.o(.text) referenced from startup_stm32f103xb.o(RESET)
- TIM3_IRQHandler from startup_stm32f103xb.o(.text) referenced from startup_stm32f103xb.o(RESET)
- TIM4_IRQHandler from startup_stm32f103xb.o(.text) referenced from startup_stm32f103xb.o(RESET)
- UART_DMAAbortOnError from stm32f1xx_hal_uart.o(i.UART_DMAAbortOnError) referenced from stm32f1xx_hal_uart.o(i.HAL_UART_IRQHandler)
- USART1_IRQHandler from stm32f1xx_it.o(i.USART1_IRQHandler) referenced from startup_stm32f103xb.o(RESET)
- USART2_IRQHandler from startup_stm32f103xb.o(.text) referenced from startup_stm32f103xb.o(RESET)
- USART3_IRQHandler from startup_stm32f103xb.o(.text) referenced from startup_stm32f103xb.o(RESET)
- USBD_FS_ConfigStrDescriptor from usbd_desc.o(i.USBD_FS_ConfigStrDescriptor) referenced 2 times from usbd_desc.o(.data)
- USBD_FS_DeviceDescriptor from usbd_desc.o(i.USBD_FS_DeviceDescriptor) referenced 2 times from usbd_desc.o(.data)
- USBD_FS_InterfaceStrDescriptor from usbd_desc.o(i.USBD_FS_InterfaceStrDescriptor) referenced 2 times from usbd_desc.o(.data)
- USBD_FS_LangIDStrDescriptor from usbd_desc.o(i.USBD_FS_LangIDStrDescriptor) referenced 2 times from usbd_desc.o(.data)
- USBD_FS_ManufacturerStrDescriptor from usbd_desc.o(i.USBD_FS_ManufacturerStrDescriptor) referenced 2 times from usbd_desc.o(.data)
- USBD_FS_ProductStrDescriptor from usbd_desc.o(i.USBD_FS_ProductStrDescriptor) referenced 2 times from usbd_desc.o(.data)
- USBD_FS_SerialStrDescriptor from usbd_desc.o(i.USBD_FS_SerialStrDescriptor) referenced 2 times from usbd_desc.o(.data)
- USBD_HID_DataIn from usbd_hid.o(i.USBD_HID_DataIn) referenced 2 times from usbd_hid.o(.data)
- USBD_HID_DeInit from usbd_hid.o(i.USBD_HID_DeInit) referenced 2 times from usbd_hid.o(.data)
- USBD_HID_GetDeviceQualifierDesc from usbd_hid.o(i.USBD_HID_GetDeviceQualifierDesc) referenced 2 times from usbd_hid.o(.data)
- USBD_HID_GetFSCfgDesc from usbd_hid.o(i.USBD_HID_GetFSCfgDesc) referenced 2 times from usbd_hid.o(.data)
- USBD_HID_GetHSCfgDesc from usbd_hid.o(i.USBD_HID_GetHSCfgDesc) referenced 2 times from usbd_hid.o(.data)
- USBD_HID_GetOtherSpeedCfgDesc from usbd_hid.o(i.USBD_HID_GetOtherSpeedCfgDesc) referenced 2 times from usbd_hid.o(.data)
- USBD_HID_Init from usbd_hid.o(i.USBD_HID_Init) referenced 2 times from usbd_hid.o(.data)
- USBD_HID_Setup from usbd_hid.o(i.USBD_HID_Setup) referenced 2 times from usbd_hid.o(.data)
- USBWakeUp_IRQHandler from startup_stm32f103xb.o(.text) referenced from startup_stm32f103xb.o(RESET)
- USB_HP_CAN1_TX_IRQHandler from startup_stm32f103xb.o(.text) referenced from startup_stm32f103xb.o(RESET)
- USB_LP_CAN1_RX0_IRQHandler from stm32f1xx_it.o(i.USB_LP_CAN1_RX0_IRQHandler) referenced from startup_stm32f103xb.o(RESET)
- UsageFault_Handler from stm32f1xx_it.o(i.UsageFault_Handler) referenced from startup_stm32f103xb.o(RESET)
- WWDG_IRQHandler from startup_stm32f103xb.o(.text) referenced from startup_stm32f103xb.o(RESET)
- __main from entry.o(.ARM.Collect$$$$00000000) referenced from startup_stm32f103xb.o(.text)
- fputc from main.o(i.fputc) referenced from printfb.o(i.__0printf$bare)
- main from main.o(i.main) referenced from entry9a.o(.ARM.Collect$$$$0000000B)

### Global Symbols

__main (Thumb, 0 bytes, Stack size unknown bytes, entry.o(.ARM.Collect$$$$00000000))
[Address Reference Count : 1]

- startup_stm32f103xb.o(.text)

_main_stk (Thumb, 0 bytes, Stack size unknown bytes, entry2.o(.ARM.Collect$$$$00000001))

_main_scatterload (Thumb, 0 bytes, Stack size unknown bytes, entry5.o(.ARM.Collect$$$$00000004))

[Calls]

- >> __scatterload

__main_after_scatterload (Thumb, 0 bytes, Stack size unknown bytes, entry5.o(.ARM.Collect$$$$00000004))

[Called By]

- >> __scatterload

_main_clock (Thumb, 0 bytes, Stack size unknown bytes, entry7b.o(.ARM.Collect$$$$00000008))

_main_cpp_init (Thumb, 0 bytes, Stack size unknown bytes, entry8b.o(.ARM.Collect$$$$0000000A))

_main_init (Thumb, 0 bytes, Stack size unknown bytes, entry9a.o(.ARM.Collect$$$$0000000B))

__rt_lib_shutdown_fini (Thumb, 0 bytes, Stack size unknown bytes, entry12b.o(.ARM.Collect$$$$0000000E))

__rt_final_cpp (Thumb, 0 bytes, Stack size unknown bytes, entry10a.o(.ARM.Collect$$$$0000000F))

__rt_final_exit (Thumb, 0 bytes, Stack size unknown bytes, entry11a.o(.ARM.Collect$$$$00000011))

Reset_Handler (Thumb, 8 bytes, Stack size 0 bytes, startup_stm32f103xb.o(.text))
[Address Reference Count : 1]

- startup_stm32f103xb.o(RESET)

CAN1_RX1_IRQHandler (Thumb, 0 bytes, Stack size 0 bytes, startup_stm32f103xb.o(.text))

[Calls]

- >> CAN1_RX1_IRQHandler

[Called By]

- >> CAN1_RX1_IRQHandler

[Address Reference Count : 1]

- startup_stm32f103xb.o(RESET)

CAN1_SCE_IRQHandler (Thumb, 0 bytes, Stack size 0 bytes, startup_stm32f103xb.o(.text))
[Address Reference Count : 1]

- startup_stm32f103xb.o(RESET)

DMA1_Channel1_IRQHandler (Thumb, 0 bytes, Stack size 0 bytes, startup_stm32f103xb.o(.text))
[Address Reference Count : 1]

- startup_stm32f103xb.o(RESET)

DMA1_Channel2_IRQHandler (Thumb, 0 bytes, Stack size 0 bytes, startup_stm32f103xb.o(.text))
[Address Reference Count : 1]

- startup_stm32f103xb.o(RESET)

DMA1_Channel3_IRQHandler (Thumb, 0 bytes, Stack size 0 bytes, startup_stm32f103xb.o(.text))
[Address Reference Count : 1]

- startup_stm32f103xb.o(RESET)

DMA1_Channel4_IRQHandler (Thumb, 0 bytes, Stack size 0 bytes, startup_stm32f103xb.o(.text))
[Address Reference Count : 1]

- startup_stm32f103xb.o(RESET)

DMA1_Channel5_IRQHandler (Thumb, 0 bytes, Stack size 0 bytes, startup_stm32f103xb.o(.text))
[Address Reference Count : 1]

- startup_stm32f103xb.o(RESET)

DMA1_Channel6_IRQHandler (Thumb, 0 bytes, Stack size 0 bytes, startup_stm32f103xb.o(.text))
[Address Reference Count : 1]

- startup_stm32f103xb.o(RESET)

DMA1_Channel7_IRQHandler (Thumb, 0 bytes, Stack size 0 bytes, startup_stm32f103xb.o(.text))
[Address Reference Count : 1]

- startup_stm32f103xb.o(RESET)

EXTI0_IRQHandler (Thumb, 0 bytes, Stack size 0 bytes, startup_stm32f103xb.o(.text))
[Address Reference Count : 1]

- startup_stm32f103xb.o(RESET)

EXTI15_10_IRQHandler (Thumb, 0 bytes, Stack size 0 bytes, startup_stm32f103xb.o(.text))
[Address Reference Count : 1]

- startup_stm32f103xb.o(RESET)

EXTI1_IRQHandler (Thumb, 0 bytes, Stack size 0 bytes, startup_stm32f103xb.o(.text))
[Address Reference Count : 1]

- startup_stm32f103xb.o(RESET)

EXTI2_IRQHandler (Thumb, 0 bytes, Stack size 0 bytes, startup_stm32f103xb.o(.text))
[Address Reference Count : 1]

- startup_stm32f103xb.o(RESET)

EXTI3_IRQHandler (Thumb, 0 bytes, Stack size 0 bytes, startup_stm32f103xb.o(.text))
[Address Reference Count : 1]

- startup_stm32f103xb.o(RESET)

EXTI4_IRQHandler (Thumb, 0 bytes, Stack size 0 bytes, startup_stm32f103xb.o(.text))
[Address Reference Count : 1]

- startup_stm32f103xb.o(RESET)

EXTI9_5_IRQHandler (Thumb, 0 bytes, Stack size 0 bytes, startup_stm32f103xb.o(.text))
[Address Reference Count : 1]

- startup_stm32f103xb.o(RESET)

FLASH_IRQHandler (Thumb, 0 bytes, Stack size 0 bytes, startup_stm32f103xb.o(.text))
[Address Reference Count : 1]

- startup_stm32f103xb.o(RESET)

I2C1_ER_IRQHandler (Thumb, 0 bytes, Stack size 0 bytes, startup_stm32f103xb.o(.text))
[Address Reference Count : 1]

- startup_stm32f103xb.o(RESET)

I2C1_EV_IRQHandler (Thumb, 0 bytes, Stack size 0 bytes, startup_stm32f103xb.o(.text))
[Address Reference Count : 1]

- startup_stm32f103xb.o(RESET)

I2C2_ER_IRQHandler (Thumb, 0 bytes, Stack size 0 bytes, startup_stm32f103xb.o(.text))
[Address Reference Count : 1]

- startup_stm32f103xb.o(RESET)

I2C2_EV_IRQHandler (Thumb, 0 bytes, Stack size 0 bytes, startup_stm32f103xb.o(.text))
[Address Reference Count : 1]

- startup_stm32f103xb.o(RESET)

PVD_IRQHandler (Thumb, 0 bytes, Stack size 0 bytes, startup_stm32f103xb.o(.text))
[Address Reference Count : 1]

- startup_stm32f103xb.o(RESET)

RCC_IRQHandler (Thumb, 0 bytes, Stack size 0 bytes, startup_stm32f103xb.o(.text))
[Address Reference Count : 1]

- startup_stm32f103xb.o(RESET)

RTC_Alarm_IRQHandler (Thumb, 0 bytes, Stack size 0 bytes, startup_stm32f103xb.o(.text))
[Address Reference Count : 1]

- startup_stm32f103xb.o(RESET)

RTC_IRQHandler (Thumb, 0 bytes, Stack size 0 bytes, startup_stm32f103xb.o(.text))
[Address Reference Count : 1]

- startup_stm32f103xb.o(RESET)

SPI1_IRQHandler (Thumb, 0 bytes, Stack size 0 bytes, startup_stm32f103xb.o(.text))
[Address Reference Count : 1]

- startup_stm32f103xb.o(RESET)

TAMPER_IRQHandler (Thumb, 0 bytes, Stack size 0 bytes, startup_stm32f103xb.o(.text))
[Address Reference Count : 1]

- startup_stm32f103xb.o(RESET)

TIM1_BRK_IRQHandler (Thumb, 0 bytes, Stack size 0 bytes, startup_stm32f103xb.o(.text))
[Address Reference Count : 1]

- startup_stm32f103xb.o(RESET)

TIM1_CC_IRQHandler (Thumb, 0 bytes, Stack size 0 bytes, startup_stm32f103xb.o(.text))
[Address Reference Count : 1]

- startup_stm32f103xb.o(RESET)

TIM1_TRG_COM_IRQHandler (Thumb, 0 bytes, Stack size 0 bytes, startup_stm32f103xb.o(.text))
[Address Reference Count : 1]

- startup_stm32f103xb.o(RESET)

TIM1_UP_IRQHandler (Thumb, 0 bytes, Stack size 0 bytes, startup_stm32f103xb.o(.text))
[Address Reference Count : 1]

- startup_stm32f103xb.o(RESET)

TIM2_IRQHandler (Thumb, 0 bytes, Stack size 0 bytes, startup_stm32f103xb.o(.text))
[Address Reference Count : 1]

- startup_stm32f103xb.o(RESET)

TIM3_IRQHandler (Thumb, 0 bytes, Stack size 0 bytes, startup_stm32f103xb.o(.text))
[Address Reference Count : 1]

- startup_stm32f103xb.o(RESET)

TIM4_IRQHandler (Thumb, 0 bytes, Stack size 0 bytes, startup_stm32f103xb.o(.text))
[Address Reference Count : 1]

- startup_stm32f103xb.o(RESET)

USART2_IRQHandler (Thumb, 0 bytes, Stack size 0 bytes, startup_stm32f103xb.o(.text))
[Address Reference Count : 1]

- startup_stm32f103xb.o(RESET)

USART3_IRQHandler (Thumb, 0 bytes, Stack size 0 bytes, startup_stm32f103xb.o(.text))
[Address Reference Count : 1]

- startup_stm32f103xb.o(RESET)

USBWakeUp_IRQHandler (Thumb, 0 bytes, Stack size 0 bytes, startup_stm32f103xb.o(.text))
[Address Reference Count : 1]

- startup_stm32f103xb.o(RESET)

USB_HP_CAN1_TX_IRQHandler (Thumb, 0 bytes, Stack size 0 bytes, startup_stm32f103xb.o(.text))
[Address Reference Count : 1]

- startup_stm32f103xb.o(RESET)

WWDG_IRQHandler (Thumb, 0 bytes, Stack size 0 bytes, startup_stm32f103xb.o(.text))
[Address Reference Count : 1]

- startup_stm32f103xb.o(RESET)

__aeabi_memset (Thumb, 14 bytes, Stack size 0 bytes, memseta.o(.text), UNUSED)

[Called By]

- >> _memset$wrapper
- >> __aeabi_memclr

__aeabi_memset4 (Thumb, 0 bytes, Stack size 0 bytes, memseta.o(.text), UNUSED)

__aeabi_memset8 (Thumb, 0 bytes, Stack size 0 bytes, memseta.o(.text), UNUSED)

__aeabi_memclr (Thumb, 4 bytes, Stack size 0 bytes, memseta.o(.text), UNUSED)

[Calls]

- >> __aeabi_memset

__aeabi_memclr4 (Thumb, 0 bytes, Stack size 0 bytes, memseta.o(.text))

[Called By]

- >> SystemClock_Config
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

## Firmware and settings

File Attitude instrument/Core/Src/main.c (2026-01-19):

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
/* Includes ------------------------------------------------------------------*/
#include "main.h"
#include "i2c.h"
#include "spi.h"
#include "tim.h"
#include "usart.h"
#include "gpio.h"

/* USER CODE BEGIN Includes */
#include "OLED.h"
#include "stdio.h"
#include "MPU6050driver.h" 
#include "mahony.h"
#include "ahrs.h"
#include "imu_data.h"
#include "commu.h"
#include "LED.h"
#include "NRF24L01.h"
/* USER CODE END Includes */


void SystemClock_Config(void);
/* USER CODE BEGIN 0 */

int fputc(int ch,FILE *f)
{
	uint8_t temp[1] = {ch};
	
	//采用轮询方式发送1字节数据
	HAL_UART_Transmit(&huart1,temp,1,2);
	return ch;
}


int maxduty = 0;
void HAL_TIM_PeriodElapsedCallback(TIM_HandleTypeDef *htim)
{
	if(htim->Instance==TIM2)
	{
		imuCalculateEstimatedAttitude();
		
		LED_Callback(maxduty);
		//navi_calculate();


		
	}
}
uint8_t key;
/* USER CODE END 0 */

/**
  * @brief  The application entry point.
  * @retval int
  */
int main(void)
{
  /* MCU Configuration--------------------------------------------------------*/

  /* Reset of all peripherals, Initializes the Flash interface and the Systick. */
  HAL_Init();

  /* Configure the system clock */
  SystemClock_Config();

  /* Initialize all configured peripherals */
  MX_GPIO_Init();
  MX_I2C2_Init();
  MX_USART1_UART_Init();
  MX_TIM2_Init();
  MX_SPI2_Init();
  MX_TIM1_Init();
  MX_TIM4_Init();
  /* USER CODE BEGIN 2 */
	Filter_init();
	OLED_Init();
	while(MPU_Init()==1){HAL_Delay(10);}//初始化成功跳出循环
	HAL_Delay(100);
	FusionAhrsInitialise(&ahrs);//初始化ahrs
//	OLED_ShowString(1,7,"test");
	HAL_TIM_Base_Start_IT(&htim2); 
	
	
	//NRF24L01_Init( );
	while(NRF24L01_Check())
	{
			printf("硬件查寻不到NRF24L01无线模块\r\n"); 
			HAL_Delay(1000);
	}
	printf("NRF24L01无线模块硬件连接正常\r\n");
	NRF24L01_TX_Mode();
  printf("进入数据发送模式\r\n");
	
	HAL_TIM_PWM_Start(&htim1, TIM_CHANNEL_1);
	HAL_TIM_PWM_Start(&htim4, TIM_CHANNEL_3);
	HAL_TIM_PWM_Start(&htim4, TIM_CHANNEL_4);
	
//	__HAL_TIM_SET_COMPARE(&htim1,TIM_CHANNEL_1,1000);
//	__HAL_TIM_SET_COMPARE(&htim4,TIM_CHANNEL_3,500);
//	__HAL_TIM_SET_COMPARE(&htim4,TIM_CHANNEL_4,250);
  /* USER CODE END 2 */

  /* Infinite loop */
  /* USER CODE BEGIN WHILE */
  while (1)
  {
    /* USER CODE END WHILE */

    /* USER CODE BEGIN 3 */
		
		key = KEY_Scan(1);
//		printf("%d \r\n ",key);
		switch(key)
		{
			case 3:
				if(maxduty>=1000)
					maxduty =1000;
				else
					maxduty += 20;
				break;
				
			case 6:
				if(maxduty<=0)
					maxduty =0;
				else
					maxduty -= 20;
				break;
		}
		if(imu_offset_flag)
		{
			sent_data();
		}
		OLED_ShowString(1,1,"LED:");
		OLED_ShowFNum(1, 5, maxduty/10.0f, 4, 1);
		OLED_ShowString(1,11,"%");
		OLED_ShowString(2,1,"roll");
		OLED_ShowFNum(2, 7, attitude_roll, 6, 3);
		OLED_ShowString(3,1,"pitch");
		OLED_ShowFNum(3, 7, attitude_pitch, 6, 3);
		OLED_ShowString(4,1,"yaw");
		OLED_ShowFNum(4, 7, attitude_yaw, 6, 3);
		
  }
  /* USER CODE END 3 */
}

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


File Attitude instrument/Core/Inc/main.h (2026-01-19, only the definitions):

#define SPI2_IRQ_Pin GPIO_PIN_4
#define SPI2_IRQ_GPIO_Port GPIOA
#define SPI2_CE_Pin GPIO_PIN_0
#define SPI2_CE_GPIO_Port GPIOB
#define SPI2_CSN_Pin GPIO_PIN_1
#define SPI2_CSN_GPIO_Port GPIOB
#define LED4_Pin GPIO_PIN_12
#define LED4_GPIO_Port GPIOB
#define LED1_Pin GPIO_PIN_8
#define LED1_GPIO_Port GPIOA
#define KEY1_Pin GPIO_PIN_3
#define KEY1_GPIO_Port GPIOB
#define KEY2_Pin GPIO_PIN_4
#define KEY2_GPIO_Port GPIOB
#define KEY3_Pin GPIO_PIN_5
#define KEY3_GPIO_Port GPIOB
#define LED2_Pin GPIO_PIN_8
#define LED2_GPIO_Port GPIOB
#define LED3_Pin GPIO_PIN_9
#define LED3_GPIO_Port GPIOB

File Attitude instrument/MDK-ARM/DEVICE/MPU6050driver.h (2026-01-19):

#ifndef __MPU6050DRVER_H
#define __MPU6050DRVER_H

									  	  
#include "stm32f1xx_hal.h"

//#define MPU_ACCEL_OFFS_REG		0X06	//accel_offs寄存器,可读取版本号,寄存器手册未提到
//#define MPU_PROD_ID_REG			0X0C	//prod id寄存器,在寄存器手册未提到
#define MPU_SELF_TESTX_REG		0X0D	//自检寄存器X
#define MPU_SELF_TESTY_REG		0X0E	//自检寄存器Y
#define MPU_SELF_TESTZ_REG		0X0F	//自检寄存器Z
#define MPU_SELF_TESTA_REG		0X10	//自检寄存器A
#define MPU_SAMPLE_RATE_REG		0X19	//采样频率分频器
#define MPU_CFG_REG			0X1A	//配置寄存器
#define MPU_GYRO_CFG_REG		0X1B	//陀螺仪配置寄存器
#define MPU_ACCEL_CFG_REG		0X1C	//加速度计配置寄存器
#define MPU_MOTION_DET_REG		0X1F	//运动检测阀值设置寄存器
#define MPU_FIFO_EN_REG			0X23	//FIFO使能寄存器
#define MPU_I2CMST_CTRL_REG		0X24	//IIC主机控制寄存器
#define MPU_I2CSLV0_ADDR_REG	        0X25	//IIC从机0器件地址寄存器
#define MPU_I2CSLV0_REG			0X26	//IIC从机0数据地址寄存器
#define MPU_I2CSLV0_CTRL_REG	        0X27	//IIC从机0控制寄存器
#define MPU_I2CSLV1_ADDR_REG	        0X28	//IIC从机1器件地址寄存器
#define MPU_I2CSLV1_REG			0X29	//IIC从机1数据地址寄存器
#define MPU_I2CSLV1_CTRL_REG	        0X2A	//IIC从机1控制寄存器
#define MPU_I2CSLV2_ADDR_REG	        0X2B	//IIC从机2器件地址寄存器
#define MPU_I2CSLV2_REG			0X2C	//IIC从机2数据地址寄存器
#define MPU_I2CSLV2_CTRL_REG	        0X2D	//IIC从机2控制寄存器
#define MPU_I2CSLV3_ADDR_REG	        0X2E	//IIC从机3器件地址寄存器
#define MPU_I2CSLV3_REG			0X2F	//IIC从机3数据地址寄存器
#define MPU_I2CSLV3_CTRL_REG	        0X30	//IIC从机3控制寄存器
#define MPU_I2CSLV4_ADDR_REG	        0X31	//IIC从机4器件地址寄存器
#define MPU_I2CSLV4_REG			0X32	//IIC从机4数据地址寄存器
#define MPU_I2CSLV4_DO_REG		0X33	//IIC从机4写数据寄存器
#define MPU_I2CSLV4_CTRL_REG	        0X34	//IIC从机4控制寄存器
#define MPU_I2CSLV4_DI_REG		0X35	//IIC从机4读数据寄存器

#define MPU_I2CMST_STA_REG		0X36	//IIC主机状态寄存器
#define MPU_INTBP_CFG_REG		0X37	//中断/旁路设置寄存器
#define MPU_INT_EN_REG			0X38	//中断使能寄存器
#define MPU_INT_STA_REG			0X3A	//中断状态寄存器

#define MPU_ACCEL_XOUTH_REG		0X3B	//加速度值,X轴高8位寄存器
#define MPU_ACCEL_XOUTL_REG		0X3C	//加速度值,X轴低8位寄存器
#define MPU_ACCEL_YOUTH_REG		0X3D	//加速度值,Y轴高8位寄存器
#define MPU_ACCEL_YOUTL_REG		0X3E	//加速度值,Y轴低8位寄存器
#define MPU_ACCEL_ZOUTH_REG		0X3F	//加速度值,Z轴高8位寄存器
#define MPU_ACCEL_ZOUTL_REG		0X40	//加速度值,Z轴低8位寄存器

#define MPU_TEMP_OUTH_REG		0X41	//温度值高八位寄存器
#define MPU_TEMP_OUTL_REG		0X42	//温度值低8位寄存器

#define MPU_GYRO_XOUTH_REG		0X43	//陀螺仪值,X轴高8位寄存器
#define MPU_GYRO_XOUTL_REG		0X44	//陀螺仪值,X轴低8位寄存器
#define MPU_GYRO_YOUTH_REG		0X45	//陀螺仪值,Y轴高8位寄存器
#define MPU_GYRO_YOUTL_REG		0X46	//陀螺仪值,Y轴低8位寄存器
#define MPU_GYRO_ZOUTH_REG		0X47	//陀螺仪值,Z轴高8位寄存器
#define MPU_GYRO_ZOUTL_REG		0X48	//陀螺仪值,Z轴低8位寄存器

#define MPU_I2CSLV0_DO_REG		0X63	//IIC从机0数据寄存器
#define MPU_I2CSLV1_DO_REG		0X64	//IIC从机1数据寄存器
#define MPU_I2CSLV2_DO_REG		0X65	//IIC从机2数据寄存器
#define MPU_I2CSLV3_DO_REG		0X66	//IIC从机3数据寄存器

#define MPU_I2CMST_DELAY_REG	        0X67	//IIC主机延时管理寄存器
#define MPU_SIGPATH_RST_REG		0X68	//信号通道复位寄存器
#define MPU_MDETECT_CTRL_REG	        0X69	//运动检测控制寄存器
#define MPU_USER_CTRL_REG		0X6A	//用户控制寄存器
#define MPU_PWR_MGMT1_REG		0X6B	//电源管理寄存器1
#define MPU_PWR_MGMT2_REG		0X6C	//电源管理寄存器2 
#define MPU_FIFO_CNTH_REG		0X72	//FIFO计数寄存器高八位
#define MPU_FIFO_CNTL_REG		0X73	//FIFO计数寄存器低八位
#define MPU_FIFO_RW_REG			0X74	//FIFO读写寄存器
#define MPU_DEVICE_ID_REG		0X75	//器件ID寄存器
 
//如果AD0脚(9脚)接地,IIC地址为0X68(不包含最低位).
//如果接V3.3,则IIC地址为0X69(不包含最低位).
#define MPU_ADDR				0X68


//因为开发板接GND,所以转为读写地址后,为0XD1和0XD0(如果接GND,则为0XD3和0XD2)  
#define MPU_READ    0XD1
#define MPU_WRITE   0XD0

uint8_t MPU_Init(void); 						//初始化MPU6050
uint8_t MPU_Write_Len(uint8_t reg,uint8_t len,uint8_t *buf);                           //IIC连续写
uint8_t MPU_Read_Len(uint8_t reg,uint8_t len,uint8_t *buf);                         //IIC连续读 
uint8_t MPU_Write_Byte(uint8_t reg,uint8_t data);				//IIC写一个字节
uint8_t MPU_Read_Byte(uint8_t reg);					//IIC读一个字节

uint8_t MPU_Set_Gyro_Fsr(uint8_t fsr);
uint8_t MPU_Set_Accel_Fsr(uint8_t fsr);
uint8_t MPU_Set_LPF(uint16_t lpf);
uint8_t MPU_Set_Rate(uint16_t rate);
uint8_t MPU_Set_Fifo(uint8_t sens);


float MPU_Get_Temperature(void);
uint8_t MPU_Get_Gyroscope(short *gx,short *gy,short *gz);
uint8_t MPU_Get_Accelerometer(short *ax,short *ay,short *az);

#endif

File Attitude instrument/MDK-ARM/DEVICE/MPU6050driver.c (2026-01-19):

#include "MPU6050driver.h" 

//初始化MPU6050
//返回值:0,成功
//    其他,错误代码

uint8_t MPU_Init(void)
{ 
  uint8_t res;
  extern I2C_HandleTypeDef hi2c2;
  HAL_I2C_Init(&hi2c2);
  MPU_Write_Byte(MPU_PWR_MGMT1_REG,0X80);	//复位MPU6050
	HAL_Delay (100);
  MPU_Write_Byte(MPU_PWR_MGMT1_REG,0X00);	//唤醒MPU6050 
  MPU_Set_Gyro_Fsr(3);					//陀螺仪传感器,±2000dps  16.4LSB/(°/S)
  MPU_Set_Accel_Fsr(0);					//加速度传感器,±2g       16384LSB/g
  MPU_Set_Rate(200);						//设置采样率50Hz
  MPU_Write_Byte(MPU_INT_EN_REG,0X00);	//关闭所有中断
  MPU_Write_Byte(MPU_USER_CTRL_REG,0X00);	//I2C主模式关闭
  MPU_Write_Byte(MPU_FIFO_EN_REG,0X00);	//关闭FIFO
  MPU_Write_Byte(MPU_INTBP_CFG_REG,0X80);	//INT引脚低电平有效
  res=MPU_Read_Byte(MPU_DEVICE_ID_REG);
  if(res==MPU_ADDR)//器件ID正确
  {
    MPU_Write_Byte(MPU_PWR_MGMT1_REG,0X01);	//设置CLKSEL,PLL X轴为参考
    MPU_Write_Byte(MPU_PWR_MGMT2_REG,0X00);	//加速度与陀螺仪都工作
    MPU_Set_Rate(50);						//设置采样率为50Hz
		//printf("ok");
  }else 
	{
		//printf("error");
	return 1;
	}
	//printf("ok");
  return 0;
}
//设置MPU6050陀螺仪传感器满量程范围
//fsr:0,±250dps;1,±500dps;2,±1000dps;3,±2000dps
//返回值:0,设置成功
//    其他,设置失败 
uint8_t MPU_Set_Gyro_Fsr(uint8_t fsr)
{
	return MPU_Write_Byte(MPU_GYRO_CFG_REG,fsr<<3);//设置陀螺仪满量程范围  
}
//设置MPU6050加速度传感器满量程范围
//fsr:0,±2g;1,±4g;2,±8g;3,±16g
//返回值:0,设置成功
//    其他,设置失败 
uint8_t MPU_Set_Accel_Fsr(uint8_t fsr)
{
	return MPU_Write_Byte(MPU_ACCEL_CFG_REG,fsr<<3);//设置加速度传感器满量程范围  
}
//设置MPU6050的数字低通滤波器
//lpf:数字低通滤波频率(Hz)
//返回值:0,设置成功
//    其他,设置失败 
uint8_t MPU_Set_LPF(uint16_t lpf)
{
	uint8_t data=0;
	if(lpf>=188)data=1;
	else if(lpf>=98)data=2;
	else if(lpf>=42)data=3;
	else if(lpf>=20)data=4;
	else if(lpf>=10)data=5;
	else data=6; 
	return MPU_Write_Byte(MPU_CFG_REG,data);//设置数字低通滤波器  
}
//设置MPU6050的采样率(假定Fs=1KHz)
//rate:4~1000(Hz)
//返回值:0,设置成功
//    其他,设置失败 
uint8_t MPU_Set_Rate(uint16_t rate)
{
	uint8_t data;
	if(rate>1000)rate=1000;
	if(rate<4)rate=4;
	data=1000/rate-1;
	data=MPU_Write_Byte(MPU_SAMPLE_RATE_REG,data);	//设置数字低通滤波器
 	return MPU_Set_LPF(rate/2);	//自动设置LPF为采样率的一半
}

//得到温度值
//返回值:温度值(扩大了100倍)
float MPU_Get_Temperature(void)
{
  unsigned char  buf[2]; 
  short raw;
  float temp;
  
  MPU_Read_Len(MPU_TEMP_OUTH_REG,2,buf); 
  raw=(buf[0]<<8)| buf[1];  
  temp=(36.53+((double)raw)/340)*100;  
//  temp = (long)((35 + (raw / 340)) * 65536L);
  return temp/100.0f;
}
//得到陀螺仪值(原始值)
//gx,gy,gz:陀螺仪x,y,z轴的原始读数(带符号)
//返回值:0,成功
//    其他,错误代码
uint8_t MPU_Get_Gyroscope(short *gx,short *gy,short *gz)
{
    uint8_t buf[6],res;  
	res=MPU_Read_Len(MPU_GYRO_XOUTH_REG,6,buf);
	if(res==0)
	{
		*gx=((uint16_t)buf[0]<<8)|buf[1];  
		*gy=((uint16_t)buf[2]<<8)|buf[3];  
		*gz=((uint16_t)buf[4]<<8)|buf[5];
	} 	
    return res;
}
//得到加速度值(原始值)
//gx,gy,gz:陀螺仪x,y,z轴的原始读数(带符号)
//返回值:0,成功
//    其他,错误代码
uint8_t MPU_Get_Accelerometer(short *ax,short *ay,short *az)
{
    uint8_t buf[6],res;  
	res=MPU_Read_Len(MPU_ACCEL_XOUTH_REG,6,buf);
	if(res==0)
	{
		*ax=((uint16_t)buf[0]<<8)|buf[1];  
		*ay=((uint16_t)buf[2]<<8)|buf[3];  
		*az=((uint16_t)buf[4]<<8)|buf[5];
	} 	
    return res;;
}


//IIC连续写
uint8_t MPU_Write_Len(uint8_t reg,uint8_t len,uint8_t *buf)
{
  extern I2C_HandleTypeDef hi2c2;
  HAL_I2C_Mem_Write(&hi2c2, MPU_WRITE, reg, I2C_MEMADD_SIZE_8BIT, buf, len, 0xfff);
  HAL_Delay(1);
  
  return 0;
}
//IIC连续读
//addr:器件地址
//reg:要读取的寄存器地址
//len:要读取的长度
//buf:读取到的数据存储区
//返回值:0,正常
//    其他,错误代码
uint8_t MPU_Read_Len(uint8_t reg,uint8_t len,uint8_t *buf)
{ 
  extern I2C_HandleTypeDef hi2c2;
  HAL_I2C_Mem_Read(&hi2c2, MPU_READ, reg, I2C_MEMADD_SIZE_8BIT, buf, len, 0xfff);
  //HAL_Delay(1);
  
  return 0;	
}
//IIC写一个字节 
//reg:寄存器地址
//data:数据
//返回值:0,正常
//    其他,错误代码
uint8_t MPU_Write_Byte(uint8_t reg,uint8_t data) 				 
{ 
  extern I2C_HandleTypeDef hi2c2;
  unsigned char W_Data=0;

  W_Data = data;
  HAL_I2C_Mem_Write(&hi2c2, MPU_WRITE, reg, I2C_MEMADD_SIZE_8BIT, &W_Data, 1, 0xfff);
  HAL_Delay(1);
  
  return 0;
}
//IIC读一个字节 
//reg:寄存器地址 
//返回值:读到的数据
uint8_t MPU_Read_Byte(uint8_t reg)
{
  extern I2C_HandleTypeDef hi2c2;
  unsigned char R_Data=0;
  
  HAL_I2C_Mem_Read(&hi2c2, MPU_READ, reg, I2C_MEMADD_SIZE_8BIT, &R_Data, 1, 0xfff);
  HAL_Delay(1);
  
  return R_Data;		
}

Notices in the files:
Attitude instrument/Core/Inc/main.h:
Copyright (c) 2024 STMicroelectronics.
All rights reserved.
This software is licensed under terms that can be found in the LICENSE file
